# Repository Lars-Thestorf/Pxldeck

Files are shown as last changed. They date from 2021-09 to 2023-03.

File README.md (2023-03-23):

# Pxldeck

DIY Handheld Games Console with an 32x64 Led Matrix driven by ESP32.

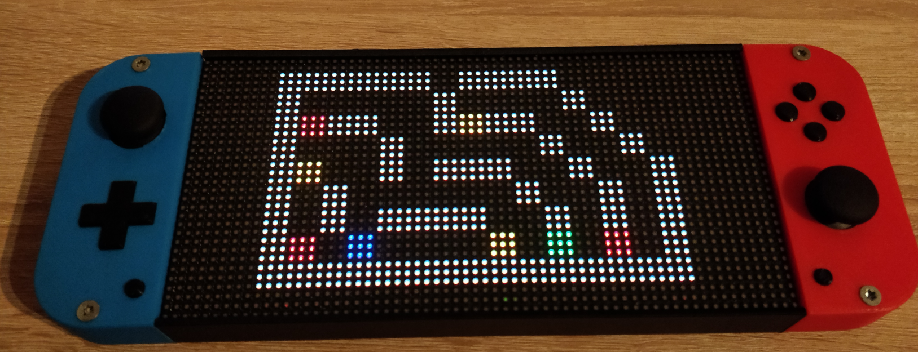
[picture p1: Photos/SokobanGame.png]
Image showing the Game Console running Sokoban Sokoban Gameplay


The Display is an P3 HUB75 LedMatrix Module.
Lots of this Modules are usally used in Advertisement Panels.
The Case is entirely 3D printed.

## Features
- 32x64 pixel screen which can be stupidly bright
- 15 buttons and two analog sticks as input
- 3000mAh battery which lasts like 10 hours
- ESP32 microcontroller providing WiFi Capabilitys, does all the gameplay processing and is driving the Screen
- ATXMega microcontroller doing battery management and input handling since the ESP just hasn't enough pins for all of that. It also serves as an USB to Uart converter so the consoles software can be updated just by plugging it into the PC.
- This Repo also contains an "Emulator" to run the games code on PC.

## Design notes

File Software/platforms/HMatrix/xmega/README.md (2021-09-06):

# Hackyprog

xmega based esp32 programmer

## Setup

	sudo apt install gcc-avr
	sudo apt install avr-libc
	git clone https://github.com/abcminiuser/lufa
	git clone this

## Build

	make

## Flash

	dfu-programmer atxmega256a3u flash VirtualSerial.hex
	#or
	avrdude -c avrisp2 -p x256a3u -U flash:w:VirtualSerial.hex
avrdude -c avrisp2 -p x128a4u -U flash:w:VirtualSerial.hex

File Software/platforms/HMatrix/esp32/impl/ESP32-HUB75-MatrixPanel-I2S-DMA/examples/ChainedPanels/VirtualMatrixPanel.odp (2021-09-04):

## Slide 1

4

3

64x32

64x32

Standard Use – Horizontal ‘chained’ LED matrix panels

(example with 4 x (64w x 32h px) LED matrix panels chained in series)

Pixel (0,0)

64x32

In your code / sketch:

#define PANEL_RES_X 64
#define PANEL_RES_X 32
#define PANEL_CHAIN 4

HUB75_I2S_CFG mxconfig (PANEL_RES_X, PANEL_RES_Y, PANEL_CHAIN);

4

3

64x32

2

64x32

64x32

1

Note: ‘VirtualMatrixPanel’ usage is not required for a simple horizontal chain!

Non-Standard Use - Using the ‘VirtualMatrixPanel’ to combine panels into a larger display

(refer to the ‘ChainedPanels’ example sketch in the examples folder)

Example 1) Top-right DOWN serpentine ‘S’ chain

Pixel (0,0)

64x32

2

64x32

1

2 x 2 (128x64)

#define NUM_ROWS 2

#define NUM_COLS 2
#define PANEL_RES_X 64
#define PANEL_RES_Y 32

#define SERPENT true

#define TOPDOWN false

/* Create physical dma output class AND virtual (chained) display class. */

#include <ESP32-VirtualMatrixPanel-I2S-DMA.h>

RGB64x32MatrixPanel_I2S_DMA dma_display;

VirtualMatrixPanel virtualDisp(dma_display, NUM_ROWS, NUM_COLS, PANEL_RES_X, PANEL_RES_Y, SERPENT, TOPDOWN);

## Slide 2

2

1

64x32

64x32

Non-Standard Use - Using the ‘VirtualMatrixPanel’ to combine panels into a larger display

(refer to the ‘ChainedPanels’ example sketch in the examples folder)

Example 2) Bottom-left UP serpentine ‘S’ chain

Pixel (0,0)

4

64x32

64x32

3

2 x 2 (128x64)

#define NUM_ROWS 2

#define NUM_COLS 2
#define PANEL_RES_X 64
#define PANEL_RES_Y 32

#define SERPENT true

#define TOPDOWN false

/* Create physical dma output class AND virtual (chained) display class. */

#include <ESP32-VirtualMatrixPanel-I2S-DMA.h>

RGB64x32MatrixPanel_I2S_DMA dma_display;

VirtualMatrixPanel virtualDisp(dma_display, NUM_ROWS, NUM_COLS, PANEL_RES_X, PANEL_RES_Y, SERPENT, TOPDOWN);

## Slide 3

3

1

Non-Standard Use - Using the ‘VirtualMatrixPanel’ to combine panels into a larger display

(refer to the ‘ChainedPanels’ example sketch in the examples folder)

Example 3) Vertical serpentine ‘S’ chain / stack

Pixel (0,0)

64x32

4

4x1 (64x128)

2

#define NUM_ROWS 4

#define NUM_COLS 1
#define PANEL_RES_X 64
#define PANEL_RES_Y 32

#define SERPENT true

/* Create physical dma output class AND virtual (chained) display class. */

#include <ESP32-VirtualMatrixPanel-I2S-DMA.h>

RGB64x32MatrixPanel_I2S_DMA dma_display;

VirtualMatrixPanel virtualDisp(dma_display, NUM_ROWS, NUM_COLS, PANEL_RES_X, PANEL_RES_Y, SERPENT);

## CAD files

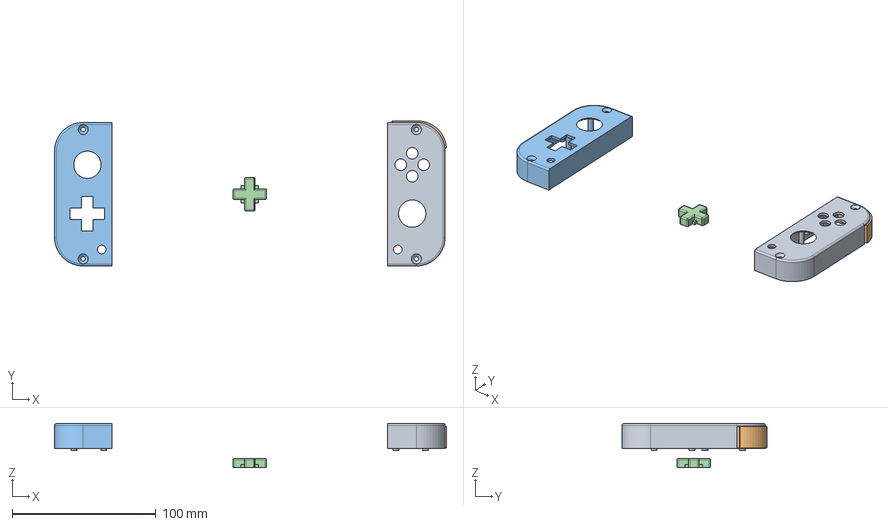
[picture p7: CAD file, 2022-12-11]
Hardware/Case/LaLeMa.FCStd
273.0 x 101.0 x 30.8 mm
Rcon
Sbtn
Lcon
Dbtn

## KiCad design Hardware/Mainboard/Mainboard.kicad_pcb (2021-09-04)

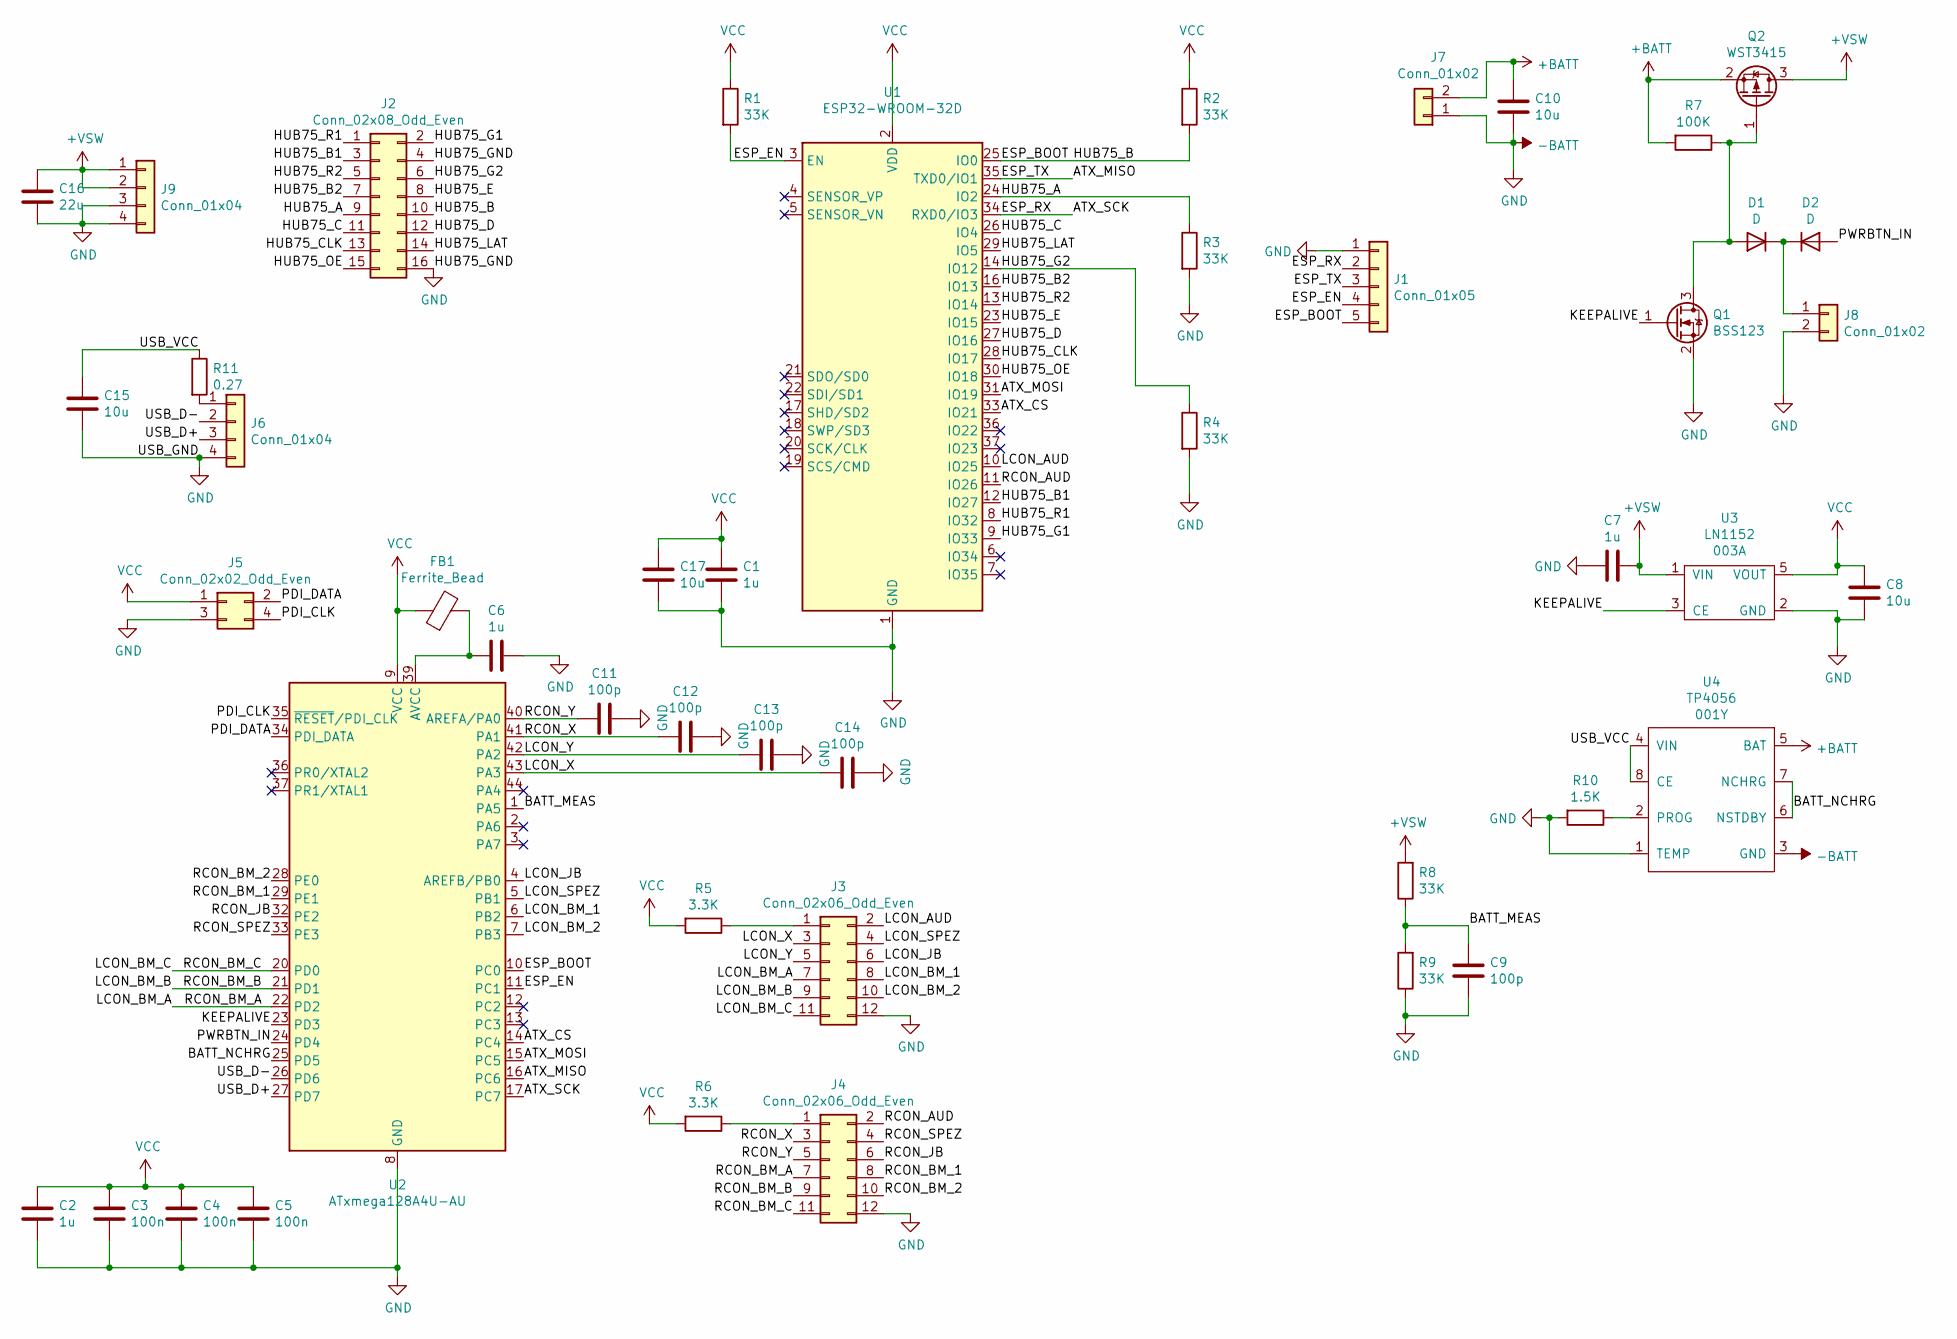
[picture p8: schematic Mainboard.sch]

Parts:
C1, C2, C6, C7: 1u; C_0402_1005Metric
C3, C4, C5: 100n; C_0402_1005Metric
C8: 10u; C_0805_2012Metric
C9, C11, C12, C13, C14: 100p; C_0402_1005Metric
C10, C15: 10u; C_0603_1608Metric
C16: 22u; C_1206_3216Metric
C17: 10u; C_0402_1005Metric
D1, D2: D; D_0603_1608Metric
FB1: Ferrite_Bead; L_0603_1608Metric
J1: Conn_01x05; PinHeader_1x05_P1.27mm_Vertical
J2: Conn_02x08_Odd_Even; PinSocket_2x08_P2.54mm_Vertical
J3, J4: Conn_02x06_Odd_Even; PinHeader_2x06_P2.54mm_Horizontal
J5: Conn_02x02_Odd_Even; PinHeader_2x02_P2.54mm_Vertical
J6, J9: Conn_01x04; PinHeader_1x04_P2.54mm_Vertical
J7, J8: Conn_01x02; PinHeader_1x02_P2.54mm_Vertical
Q1: BSS123; SOT-23
Q2: WST3415; TSOT-23
R1, R2, R3, R4, R8, R9: 33K; R_0402_1005Metric
R5, R6: 3.3K; R_0402_1005Metric
R7: 100K; R_0402_1005Metric
R10: 1.5K; R_0402_1005Metric
R11: 0.27; R_0805_2012Metric
U1: ESP32-WROOM-32D; ESP32-WROOM-32E
U2: ATxmega128A4U-AU; TQFP-44_10x10mm_P0.8mm
U3: LN1152; SOT-23-5
U4: TP4056; HSOP-8-1EP_3.9x4.9mm_P1.27mm_EP2.41x3.1mm_ThermalVias

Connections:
+BATT: C10.1, J7.2, Q2.2 (S), R7.2, U4.5 (BAT)
+VSW: C7.1, C16.1, J9.1, J9.2, Q2.3 (D), R8.2, U3.1 (VIN)
-BATT: C1.2, C2.2, C3.2, C4.2, C5.2, C6.1, C7.2, C8.2, C9.2, C10.2, C11.1, C12.1, C13.1, C14.1, C15.2, C16.2, C17.2, J1.1, J2.4, J2.16, J3.12, J4.12, J5.3, J6.4, J7.1, J8.2, J9.3, J9.4, Q1.2 (S), R3.2, R4.2, R9.1, R10.2, U1.1 (GND), U1.15 (GND), U1.38 (GND), U1.39 (GND), U2.8 (GND), U2.18 (GND), U2.30 (GND), U2.38 (GND), U3.2 (GND), U4.1 (TEMP), U4.3 (GND), U4.9 (GND)
/ATX_CS: U1.33 (IO21), U2.14 (PC4)
/ATX_MISO: J1.3, U1.35 (TXD0/IO1), U2.16 (PC6)
/ATX_MOSI: U1.31 (IO19), U2.15 (PC5)
/ATX_SCK: J1.2, U1.34 (RXD0/IO3), U2.17 (PC7)
/BATT_MEAS: C9.1, R8.1, R9.2, U2.1 (PA5)
/BATT_NCHRG: U2.25 (PD5), U4.6 (NSTDBY), U4.7 (NCHRG)
/ESP_BOOT: J1.5, J2.10, R2.2, U1.25 (IO0), U2.10 (PC0)
/ESP_EN: J1.4, R1.2, U1.3 (EN), U2.11 (PC1)
/HUB75_A: J2.9, R3.1, U1.24 (IO2)
/HUB75_B1: J2.3, U1.12 (IO27)
/HUB75_B2: J2.7, U1.16 (IO13)
/HUB75_C: J2.11, U1.26 (IO4)
/HUB75_CLK: J2.13, U1.28 (IO17)
/HUB75_D: J2.12, U1.27 (IO16)
/HUB75_E: J2.8, U1.23 (IO15)
/HUB75_G1: J2.2, U1.9 (IO33)
/HUB75_G2: J2.6, R4.1, U1.14 (IO12)
/HUB75_LAT: J2.14, U1.29 (IO5)
/HUB75_OE: J2.15, U1.30 (IO18)
/HUB75_R1: J2.1, U1.8 (IO32)
/HUB75_R2: J2.5, U1.13 (IO14)
/KEEPALIVE: Q1.1 (G), U2.23 (PD3), U3.3 (CE)
/LCON_AUD: J3.2, U1.10 (IO25)
/LCON_BM_1: J3.8, U2.6 (PB2)
/LCON_BM_2: J3.10, U2.7 (PB3)
/LCON_BM_A: J3.7, J4.7, U2.22 (PD2)
/LCON_BM_B: J3.9, J4.9, U2.21 (PD1)
/LCON_BM_C: J3.11, J4.11, U2.20 (PD0)
/LCON_JB: J3.6, U2.4 (AREFB/PB0)
/LCON_SPEZ: J3.4, U2.5 (PB1)
/LCON_X: C14.2, J3.3, U2.43 (PA3)
/LCON_Y: C13.2, J3.5, U2.42 (PA2)
/PDI_CLK: J5.4, U2.35 (~RESET~/PDI_CLK)
/PDI_DATA: J5.2, U2.34 (PDI_DATA)
/PWRBTN_IN: D2.2 (A), U2.24 (PD4)
/RCON_AUD: J4.2, U1.11 (IO26)
/RCON_BM_1: J4.8, U2.29 (PE1)
/RCON_BM_2: J4.10, U2.28 (PE0)
/RCON_JB: J4.6, U2.32 (PE2)
/RCON_SPEZ: J4.4, U2.33 (PE3)
/RCON_X: C12.2, J4.3, U2.41 (PA1)
/RCON_Y: C11.2, J4.5, U2.40 (AREFA/PA0)
/USB_D+: J6.3, U2.27 (PD7)
/USB_D-: J6.2, U2.26 (PD6)
/USB_VCC: C15.1, R11.1, U4.4 (VIN), U4.8 (CE)
unnamed: C6.2, FB1.2, U2.39 (AVCC)
unnamed: D1.1 (K), D2.1 (K), J8.1
unnamed: D1.2 (A), Q1.3 (D), Q2.1 (G), R7.1
unnamed: J3.1, R5.1
unnamed: J4.1, R6.1
unnamed: J6.1, R11.2
unnamed: R10.1, U4.2 (PROG)
VCC: C1.1, C2.1, C3.1, C4.1, C5.1, C8.1, C17.1, FB1.1, J5.1, R1.1, R2.1, R5.2, R6.2, U1.2 (VDD), U2.9 (VCC), U2.19 (VCC), U2.31 (VCC), U3.5 (VOUT)

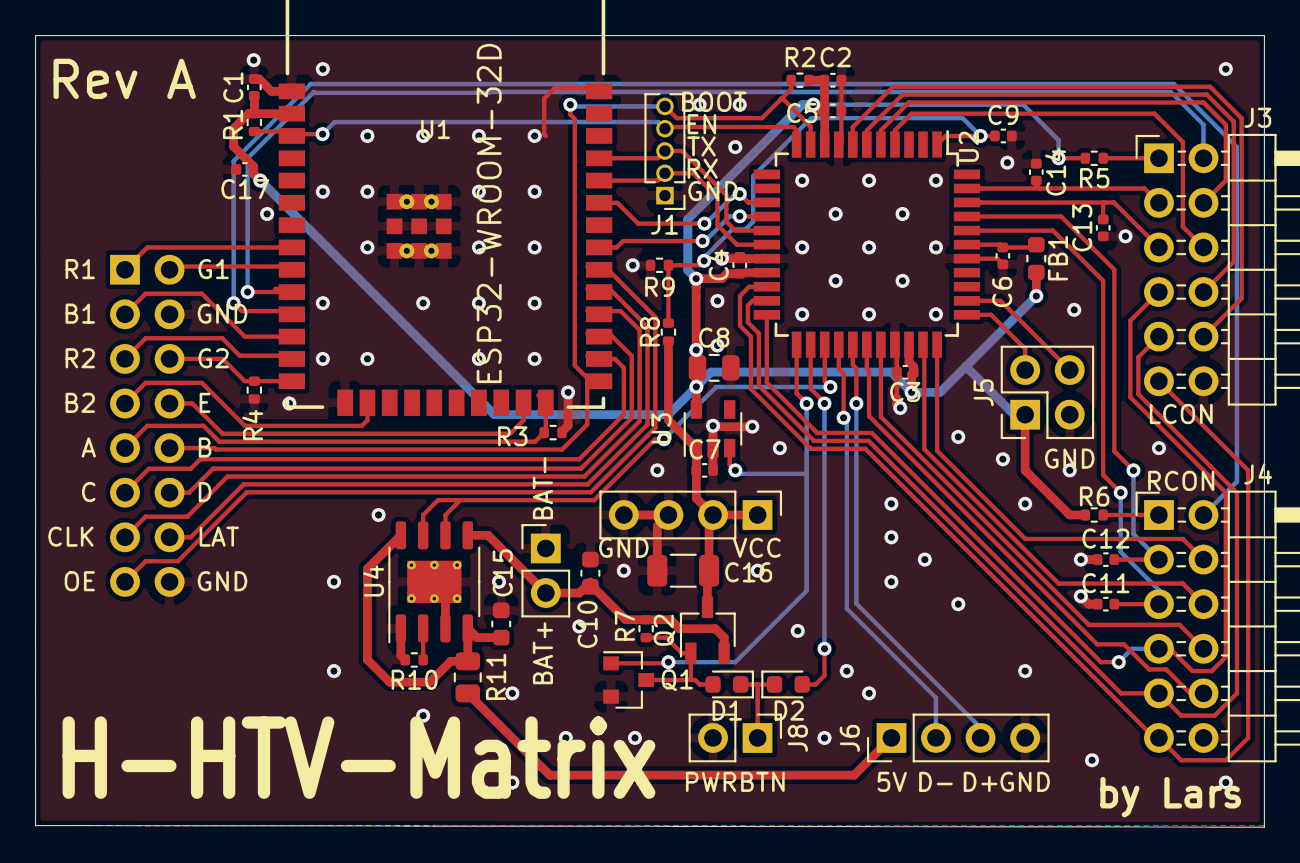
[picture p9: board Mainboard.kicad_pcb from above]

Board: 2 copper layers, 70.0 x 45.1 mm, 46 parts (1 on the bottom side), 56 nets.

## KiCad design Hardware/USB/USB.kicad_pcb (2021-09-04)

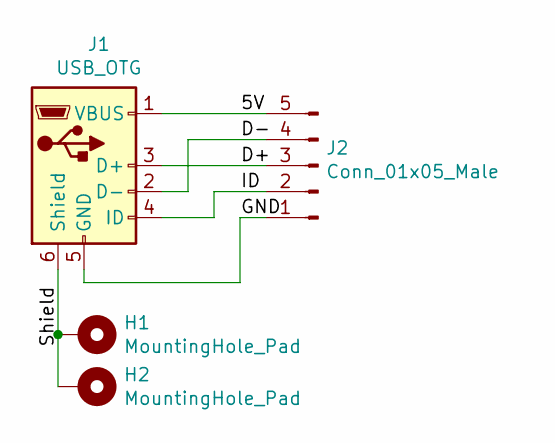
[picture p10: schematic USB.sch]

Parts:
H1, H2: MountingHole_Pad; MountingHole_2.2mm_M2_Pad
J1: USB_OTG; USB_Micro-B_Wuerth_629105150521
J2: Conn_01x05_Male; PinHeader_1x05_P2.54mm_Vertical

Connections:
/5V: J1.1 (VBUS), J2.5
/D+: J1.3 (D+), J2.3
/D-: J1.2 (D-), J2.4
/GND: J1.5 (GND), J2.1
/ID: J1.4 (ID), J2.2
/Shield: H1.1, H2.1, J1.6 (Shield)

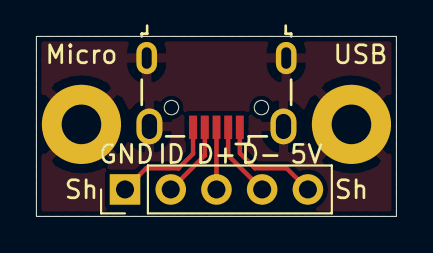
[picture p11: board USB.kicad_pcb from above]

Board: 2 copper layers, 20.0 x 10.0 mm, 4 parts (0 on the bottom side), 6 nets.

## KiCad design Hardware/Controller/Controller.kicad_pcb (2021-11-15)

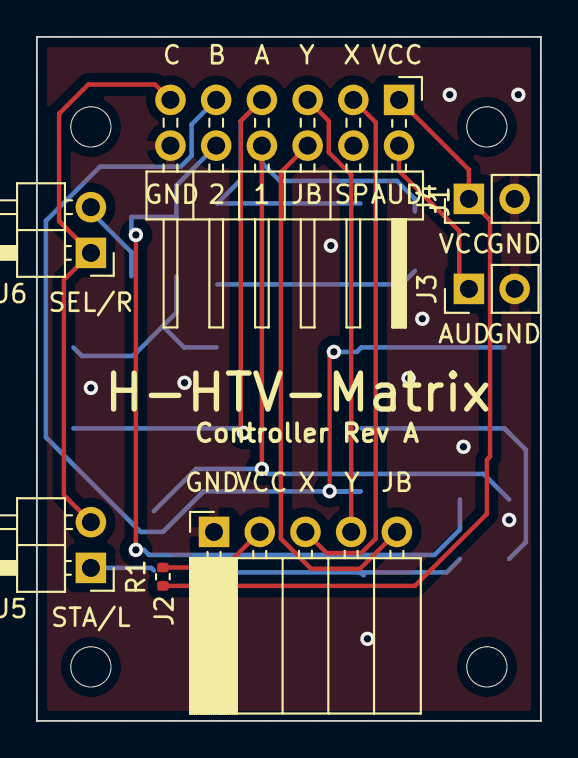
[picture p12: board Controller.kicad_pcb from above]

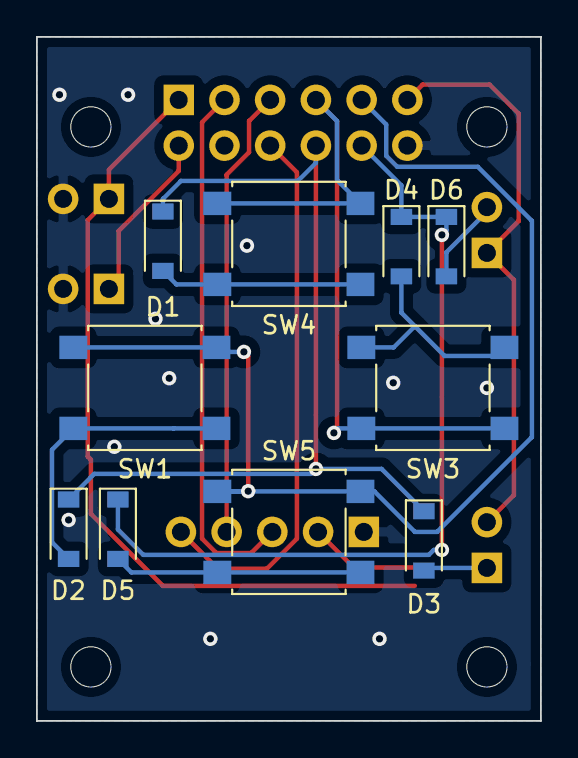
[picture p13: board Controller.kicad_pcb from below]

Board: 2 copper layers, 28.0 x 38.0 mm, 17 parts (10 on the bottom side), 18 nets.

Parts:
D1, D2, D3, D4, D5, D6: D; D_SOD-123
J1: Conn_02x06_Odd_Even; PinHeader_2x06_P2.54mm_Horizontal
J2: Conn_01x05_Female; PinSocket_1x05_P2.54mm_Horizontal
J3, J4: Conn_01x02_Male; PinHeader_1x02_P2.54mm_Vertical
J5, J6: Conn_01x02_Male; PinHeader_1x02_P2.54mm_Horizontal
R1: R; R_0402_1005Metric
SW1, SW3, SW4, SW5: SW_SPST; SW_SPST_B3S-1000

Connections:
+3V3: J1.1, J4.1, R1.2
/CON_AUD: J1.2, J3.1
/CON_BM1: D1.1, D2.1, D3.1, J1.8
/CON_BM2: D4.1, D5.1, D6.1, J1.10
/CON_BMA: J1.7, SW3.1, SW4.2
/CON_BMB: J1.9, SW1.2, SW5.1
/CON_BMC: J1.11, J5.2, J6.1
/CON_JB: J1.6, J2.5
/CON_X: J1.3, J2.3
/CON_Y: J1.5, J2.4
GND: J1.12, J2.1, J3.2, J4.2
unnamed: D1.2, SW4.1
unnamed: D2.2, SW1.1
unnamed: D3.2, J5.1
unnamed: D4.2, SW3.2
unnamed: D5.2, SW5.2
unnamed: D6.2, J6.2
unnamed: J2.2, R1.1

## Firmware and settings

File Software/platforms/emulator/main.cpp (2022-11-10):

#include <SDL2/SDL.h>
#include <stdio.h>
#include "graphics.h"
#include <HLM_graphics.h>
//#include "../HMatrix/esp32/main/bootlogo.c"
#include <HLM_os.h>
#include <HLM_random.h>
#include "input.h"

int main()
{
    graphics_init();
    graphics_drawpixel(1,1,0xFFFF);
	//graphics_drawImage1Bit(0, 0, bootlogo, 64, 32, 0x0000, 0xFFFF);

	printf("Die heutige Zahl des Tages: %d\n", HLM_random(42));
	
	os_init();
    
	SDL_Event event;
	// Events mangement
	while(true)
	{
		while (SDL_PollEvent(&event))
		{
			switch (event.type)
			{
				case SDL_QUIT: // handling of close button
					graphics_uninit();
					return 0;
				case SDL_KEYDOWN:
					switch (event.key.keysym.sym)
					{
						case SDLK_UP: setButtonPressed(BUTTON_DU, true); break;
						case SDLK_DOWN: setButtonPressed(BUTTON_DD, true); break;
						case SDLK_RIGHT: setButtonPressed(BUTTON_DR, true); break;
						case SDLK_LEFT: setButtonPressed(BUTTON_DL, true); break;
						case SDLK_d: setButtonPressed(BUTTON_PRIMARY, true); break;
						case SDLK_f: setButtonPressed(BUTTON_COPRIMARY, true); break;
						case SDLK_a: setButtonPressed(BUTTON_SECONDARY, true); break;
						case SDLK_s: setButtonPressed(BUTTON_COSECONDARY, true); break;
						case SDLK_q: setButtonPressed(BUTTON_LSHOULDER, true); break;
						case SDLK_e: setButtonPressed(BUTTON_RSHOULDER, true); break;
						case SDLK_y: setButtonPressed(BUTTON_LMENU, true); break;
						case SDLK_x: setButtonPressed(BUTTON_HOME, true); break;
						case SDLK_c: setButtonPressed(BUTTON_RMENU, true); break;
					}
					break;
				case SDL_KEYUP:
					switch (event.key.keysym.sym)
					{
						case SDLK_UP: setButtonPressed(BUTTON_DU, false); break;
						case SDLK_DOWN: setButtonPressed(BUTTON_DD, false); break;
						case SDLK_RIGHT: setButtonPressed(BUTTON_DR, false); break;
						case SDLK_LEFT: setButtonPressed(BUTTON_DL, false); break;
						case SDLK_d: setButtonPressed(BUTTON_PRIMARY, false); break;
						case SDLK_f: setButtonPressed(BUTTON_COPRIMARY, false); break;
						case SDLK_a: setButtonPressed(BUTTON_SECONDARY, false); break;
						case SDLK_s: setButtonPressed(BUTTON_COSECONDARY, false); break;
						case SDLK_q: setButtonPressed(BUTTON_LSHOULDER, false); break;
						case SDLK_e: setButtonPressed(BUTTON_RSHOULDER, false); break;
						case SDLK_y: setButtonPressed(BUTTON_LMENU, false); break;
						case SDLK_x: setButtonPressed(BUTTON_HOME, false); break;
						case SDLK_c: setButtonPressed(BUTTON_RMENU, false); break;
					}
					break;
				/*case SDL_MOUSEBUTTONDOWN:
					if (event.button.which != SDL_TOUCH_MOUSEID)
					{
						uint16_t x,y;
						x = event.button.x / DISPLAY_ZOOM;
						y = event.button.y / DISPLAY_ZOOM;
						BaReCo_touchdown(BaReCo_getActualX(x, y), BaReCo_getActualY(x, y));
					}
					break;
				case SDL_MOUSEBUTTONUP:
					if (event.button.which != SDL_TOUCH_MOUSEID)
					{
						uint16_t x,y;
						x = event.button.x / DISPLAY_ZOOM;
						y = event.button.y / DISPLAY_ZOOM;
						BaReCo_touchup(BaReCo_getActualX(x, y), BaReCo_getActualY(x, y));
					}
					break;
				case SDL_MOUSEMOTION:
					if (event.button.which != SDL_TOUCH_MOUSEID) {
						if (SDL_GetMouseState(NULL, NULL) & SDL_BUTTON(SDL_BUTTON_LEFT)){
							uint16_t x,y;
							x = event.button.x / DISPLAY_ZOOM;
							y = event.button.y / DISPLAY_ZOOM;
							BaReCo_touchmove(BaReCo_getActualX(x, y), BaReCo_getActualY(x, y));
						}
					}
					break;*/
			}
		}
		os_loop();
		graphics_render();
	}
}

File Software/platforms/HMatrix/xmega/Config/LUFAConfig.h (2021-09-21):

/*
             LUFA Library
     Copyright (C) Dean Camera, 2020.

  dean [at] fourwalledcubicle [dot] com
           www.lufa-lib.org
*/

/*
  Copyright 2020  Dean Camera (dean [at] fourwalledcubicle [dot] com)

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
  The author disclaims all warranties with regard to this
  software, including all implied warranties of merchantability
  and fitness.  In no event shall the author be liable for any
  special, indirect or consequential damages or any damages
  whatsoever resulting from loss of use, data or profits, whether
  in an action of contract, negligence or other tortious action,
  arising out of or in connection with the use or performance of
  this software.
*/

/** \file
 *  \brief LUFA Library Configuration Header File
 *
 *  This header file is used to configure LUFA's compile time options,
 *  as an alternative to the compile time constants supplied through
 *  a makefile.
 *
 *  For information on what each token does, refer to the LUFA
 *  manual section "Summary of Compile Tokens".
 */

#ifndef _LUFA_CONFIG_H_
#define _LUFA_CONFIG_H_

	#if (ARCH == ARCH_AVR8)

		/* Non-USB Related Configuration Tokens: */
//		#define DISABLE_TERMINAL_CODES

		/* USB Class Driver Related Tokens: */
//		#define HID_HOST_BOOT_PROTOCOL_ONLY
//		#define HID_STATETABLE_STACK_DEPTH       {Insert Value Here}
//		#define HID_USAGE_STACK_DEPTH            {Insert Value Here}
//		#define HID_MAX_COLLECTIONS              {Insert Value Here}
//		#define HID_MAX_REPORTITEMS              {Insert Value Here}
//		#define HID_MAX_REPORT_IDS               {Insert Value Here}
//		#define NO_CLASS_DRIVER_AUTOFLUSH

		/* General USB Driver Related Tokens: */
//		#define ORDERED_EP_CONFIG
		#define USE_STATIC_OPTIONS               (USB_DEVICE_OPT_FULLSPEED | USB_OPT_REG_ENABLED | USB_OPT_AUTO_PLL)
		#define USB_DEVICE_ONLY
//		#define USB_HOST_ONLY
//		#define USB_STREAM_TIMEOUT_MS            {Insert Value Here}
//		#define NO_LIMITED_CONTROLLER_CONNECT
//		#define NO_SOF_EVENTS

		/* USB Device Mode Driver Related Tokens: */
//		#define USE_RAM_DESCRIPTORS
		#define USE_FLASH_DESCRIPTORS
//		#define USE_EEPROM_DESCRIPTORS
//		#define NO_INTERNAL_SERIAL
		#define FIXED_CONTROL_ENDPOINT_SIZE      8
//		#define DEVICE_STATE_AS_GPIOR            {Insert Value Here}
		#define FIXED_NUM_CONFIGURATIONS         1
//		#define CONTROL_ONLY_DEVICE
//		#define INTERRUPT_CONTROL_ENDPOINT
//		#define NO_DEVICE_REMOTE_WAKEUP
//		#define NO_DEVICE_SELF_POWER

		/* USB Host Mode Driver Related Tokens: */
//		#define HOST_STATE_AS_GPIOR              {Insert Value Here}
//		#define USB_HOST_TIMEOUT_MS              {Insert Value Here}
//		#define HOST_DEVICE_SETTLE_DELAY_MS	     {Insert Value Here}
//		#define NO_AUTO_VBUS_MANAGEMENT
//		#define INVERTED_VBUS_ENABLE_LINE

	#elif (ARCH == ARCH_XMEGA)

		/* Non-USB Related Configuration Tokens: */
//		#define DISABLE_TERMINAL_CODES

		/* USB Class Driver Related Tokens: */
//		#define HID_HOST_BOOT_PROTOCOL_ONLY
//		#define HID_STATETABLE_STACK_DEPTH       {Insert Value Here}
//		#define HID_USAGE_STACK_DEPTH            {Insert Value Here}
//		#define HID_MAX_COLLECTIONS              {Insert Value Here}
//		#define HID_MAX_REPORTITEMS              {Insert Value Here}
//		#define HID_MAX_REPORT_IDS               {Insert Value Here}
//		#define NO_CLASS_DRIVER_AUTOFLUSH

		/* General USB Driver Related Tokens: */
		#define USE_STATIC_OPTIONS               (USB_DEVICE_OPT_FULLSPEED | USB_OPT_RC32MCLKSRC | USB_OPT_BUSEVENT_PRIHIGH)
//		#define USB_STREAM_TIMEOUT_MS            {Insert Value Here}
		#define NO_LIMITED_CONTROLLER_CONNECT
//		#define NO_SOF_EVENTS

		/* USB Device Mode Driver Related Tokens: */
//		#define USE_RAM_DESCRIPTORS
		#define USE_FLASH_DESCRIPTORS
//		#define USE_EEPROM_DESCRIPTORS
//		#define NO_INTERNAL_SERIAL
		#define FIXED_CONTROL_ENDPOINT_SIZE      8
//		#define DEVICE_STATE_AS_GPIOR            {Insert Value Here}
		#define FIXED_NUM_CONFIGURATIONS         1
//		#define CONTROL_ONLY_DEVICE
		#define MAX_ENDPOINT_INDEX               4
//		#define NO_DEVICE_REMOTE_WAKEUP
//		#define NO_DEVICE_SELF_POWER

	#else

		#error Unsupported architecture for this LUFA configuration file.

	#endif
#endif

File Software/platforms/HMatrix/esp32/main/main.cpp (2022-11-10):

#include <stdio.h>

#include "freertos/FreeRTOS.h"
#include "freertos/task.h"
#include "freertos/queue.h"
#include <esp_log.h>
#include <cstring>

#include <nvs_flash.h>

#include <xmegaComm/xmegaComm.h>

#include <graphics.h>

#include <HLM_os.h>

char mtbuffer[128];

extern "C" {
	void app_main(void);
}

void app_main(void)
{
    printf("Hallo Welt");
	ESP_LOGI("TAG","TEST");
	
	esp_err_t err = nvs_flash_init();
    if (err == ESP_ERR_NVS_NO_FREE_PAGES || err == ESP_ERR_NVS_NEW_VERSION_FOUND) {
        // NVS partition was truncated and needs to be erased
        // Retry nvs_flash_init
        ESP_ERROR_CHECK(nvs_flash_erase());
        err = nvs_flash_init();
    }
    ESP_ERROR_CHECK( err );
	
	SetupXmegaComm();
	
	SetupGraphics();
	
	os_init();
	
	MatrixPanel_I2S_DMA* gfx = getGraphics();
	gfx->setPanelBrightness(10);
	
	while(1){
		if (isXmegaCommEstablished()) {
			gfx->flipDMABuffer();
			gfx->clearScreen();
			
			//DrawMainMenu();
			os_loop();
			
			gfx->showDMABuffer();
		} else {
			gfx->drawPixel(0, 31, GRAPHICS_COLOR_RED);
		}
		vTaskDelay(16 / portTICK_PERIOD_MS);
			
		//ESP_LOGI("TAG","ich versuche da was anzuzeigen");
		
		XmegaCommWorker();
		
		/*dma_display->setPanelBrightness(20);
		dma_display->fillRect(0,0,64,32,255,0,0);
		vTaskDelay(1000 / portTICK_PERIOD_MS);
		dma_display->fillRect(0,0,64,32,0,255,0);
		vTaskDelay(1000 / portTICK_PERIOD_MS);
		dma_display->fillRect(0,0,64,32,0,0,255);
		vTaskDelay(1000 / portTICK_PERIOD_MS);
		dma_display->fillRect(0,0,64,32,0,0,0);
		dma_display->fillRect(0,26,64,5,255,0,0);
		dma_display->fillRect(0,21,64,5,255,127,0);
		dma_display->fillRect(0,16,64,5,255,255,0);
		dma_display->fillRect(0,11,64,5,0,255,0);
		dma_display->fillRect(0,6,64,5,0,0,255);
		dma_display->fillRect(0,1,64,5,255,0,255);
		vTaskDelay(1000 / portTICK_PERIOD_MS);
		
		//dma_display->setBrightness8(255);
		dma_display->fillRect(0,0,64,32,0,0,0);
		dma_display->fillRect(25,0,1,32,255,255,255);
		vTaskDelay(1000 / portTICK_PERIOD_MS);
		
		dma_display->fillRect(0,0,64,32,255,255,255);
		vTaskDelay(3000 / portTICK_PERIOD_MS);*/
	}
	//dma_display->showDMABuffer();
	//dma_display->fillRect(2,2,10,10,255,255,255);
	//dma_display->showDMABuffer();
	//ESP_LOGI("TAG","ich versuche da was anzuzeigen");
}

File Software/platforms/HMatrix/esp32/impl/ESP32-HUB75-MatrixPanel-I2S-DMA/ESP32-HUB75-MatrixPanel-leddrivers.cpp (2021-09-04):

/*
  Various LED Driver chips might need some specific code for initialisation/control logic 

*/

//#include <Arduino.h>
#include <driver/gpio.h>
#include "ESP32-HUB75-MatrixPanel-I2S-DMA.h"

#define CLK_PULSE          gpio_set_level((gpio_num_t)_cfg.gpio.clk, 1); gpio_set_level((gpio_num_t)_cfg.gpio.clk, 0);

/**
 * @brief - pre-init procedures for specific led-drivers
 * this method is called before DMA/I2S setup while GPIOs
 * aint yet assigned for DMA operation
 * 
 */
void MatrixPanel_I2S_DMA::shiftDriver(const HUB75_I2S_CFG& _cfg){
    switch (_cfg.driver){
    case HUB75_I2S_CFG::ICN2038S:
    case HUB75_I2S_CFG::FM6124:
    case HUB75_I2S_CFG::FM6126A:
        fm6124init(_cfg);
        break;
    case HUB75_I2S_CFG::MBI5124:
        /* MBI5124 chips must be clocked with positive-edge, since it's LAT signal
        * resets on clock's rising edge while high
        * https://github.com/mrfaptastic/ESP32-HUB75-MatrixPanel-I2S-DMA/files/5952216/5a542453754da.pdf
        */
        m_cfg.clkphase=true;
        break;
    case HUB75_I2S_CFG::SHIFTREG:
    default:
        break;
    }
}


void MatrixPanel_I2S_DMA::fm6124init(const HUB75_I2S_CFG& _cfg){
    #if SERIAL_DEBUG 
        Serial.println( F("MatrixPanel_I2S_DMA - initializing FM6124 driver..."));
    #endif
    bool REG1[16] = {0,0,0,0,0, 1,1,1,1,1,1, 0,0,0,0,0};    // this sets global matrix brightness power
    bool REG2[16] = {0,0,0,0,0, 0,0,0,0,1,0, 0,0,0,0,0};    // a single bit enables the matrix output

    for (uint8_t _pin:{_cfg.gpio.r1, _cfg.gpio.r2, _cfg.gpio.g1, _cfg.gpio.g2, _cfg.gpio.b1, _cfg.gpio.b2, _cfg.gpio.clk, _cfg.gpio.lat, _cfg.gpio.oe}){
		gpio_reset_pin((gpio_num_t)_pin);
        gpio_set_direction((gpio_num_t)_pin, GPIO_MODE_OUTPUT);
        gpio_set_level((gpio_num_t)_pin, 0);
    }

    gpio_set_level((gpio_num_t)_cfg.gpio.oe, 1); // Disable Display

    // Send Data to control register REG1
    // this sets the matrix brightness actually
    for (int l = 0; l < PIXELS_PER_ROW; l++){
        for (uint8_t _pin:{_cfg.gpio.r1, _cfg.gpio.r2, _cfg.gpio.g1, _cfg.gpio.g2, _cfg.gpio.b1, _cfg.gpio.b2})
          gpio_set_level((gpio_num_t)_pin, REG1[l%16]);   // we have 16 bits shifters and write the same value all over the matrix array

        if (l > PIXELS_PER_ROW - 12){         // pull the latch 11 clocks before the end of matrix so that REG1 starts counting to save the value
            gpio_set_level((gpio_num_t)_cfg.gpio.lat, 1);
        }
        CLK_PULSE
    }

    // drop the latch and save data to the REG1 all over the FM6124 chips
    gpio_set_level((gpio_num_t)_cfg.gpio.lat, 0);

    // Send Data to control register REG2 (enable LED output)
    for (int l = 0; l < PIXELS_PER_ROW; l++){
        for (uint8_t _pin:{_cfg.gpio.r1, _cfg.gpio.r2, _cfg.gpio.g1, _cfg.gpio.g2, _cfg.gpio.b1, _cfg.gpio.b2})
          gpio_set_level((gpio_num_t)_pin, REG2[l%16]);   // we have 16 bits shifters and we write the same value all over the matrix array

        if (l > PIXELS_PER_ROW - 13){       // pull the latch 12 clocks before the end of matrix so that reg2 stars counting to save the value
            gpio_set_level((gpio_num_t)_cfg.gpio.lat, 1);
        }
        CLK_PULSE
    }

    // drop the latch and save data to the REG1 all over the FM6126 chips
    gpio_set_level((gpio_num_t)_cfg.gpio.lat, 0);

    // blank data regs to keep matrix clear after manipulations
    for (uint8_t _pin:{_cfg.gpio.r1, _cfg.gpio.r2, _cfg.gpio.g1, _cfg.gpio.g2, _cfg.gpio.b1, _cfg.gpio.b2})
       gpio_set_level((gpio_num_t)_pin, 0);

    for (int l = 0; l < PIXELS_PER_ROW; ++l){
        CLK_PULSE
    }

    gpio_set_level((gpio_num_t)_cfg.gpio.lat, 1);
    CLK_PULSE
    gpio_set_level((gpio_num_t)_cfg.gpio.lat, 0);
    gpio_set_level((gpio_num_t)_cfg.gpio.oe, 0); // Enable Display
    CLK_PULSE
}

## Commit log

2021-08-07 Initial commit2
    [Mainboard.kicad_pcb, Mainboard.sch]
2021-08-08 power management
    [Mainboard.kicad_pcb, Mainboard.sch]
2021-08-15 Mainboard finished?
    [Mainboard.kicad_pcb, Mainboard.sch]
2021-08-16 more powerfull main pfet
    [Mainboard.kicad_pcb, Mainboard.sch]
2021-09-04 add case and code
    [LaLeMa.FCStd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]
2021-09-06 xmega as hackyprog
    [i2s_memcalc.xlsm]
2021-09-11 uart comm
2021-09-12 button comm working
2021-09-18 new power button interrupt
2021-09-25 make pong more fun and joystick calibration
2021-11-15 Add controller PCB
    [Controller-B_Cu.gbr, Controller-B_Mask.gbr, Controller-B_Paste.gbr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]
2021-11-21 Changes related to new Controller pcb#
    [LaLeMa.FCStd]
2021-12-18 start refactoring for getting emulator to work
    [Controller-B_Cu.gbr, Controller-B_Mask.gbr, Controller-B_Paste.gbr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]
2022-11-10 lots of rework on HMatrix software architecture
    [i2s_memcalc.xlsm]
2022-12-11 new button tolerances
    [LaLeMa.FCStd]
